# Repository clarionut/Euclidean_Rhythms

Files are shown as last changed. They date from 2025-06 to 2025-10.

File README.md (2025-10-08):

# Euclidean Rhythms
Euclidean Rhythms

This repository contains details of my derivative of [Hagiwo's Euclidean Rhythms](https://note.com/solder_state/n/n433b32ea6dbc) synthesiser module.

In his notes about the module, Hagiwo comments that there is considerable latency due to the OLED display and also mentions instability in the program
possibly caused by memory issues. He partially addresses the latency issue by only updating the OLED on clock inputs, but this makes it difficult to
update the settings in the absence of a clock input.
During analysis of the code I found several things which would compound these issues, e.g.
- use of a relatively slow I2C OLED display. Swapped for an alternative using much faster hardware SPI
- (using a graphics library which keeps an in-memory copy of the display. Changed to the less memory-intensive U8glib library). Subsequent testing has shown that code using the Adafruit_SSD1306 library runs roughly twice as fast as either u8glib or u8g2. I'd therefore recommend using the EuclideanRhythms_AF sketch. It's larger than the u8glib based code but has shown no signs of instability despite its greater functionality
- the original code uses multiple loops over the channels, each processing a single aspect of the code. Restructured to carry out as many of these
operations as possible in a single loop
- use of the Arduino digitalWrite() function (intrinsically very slow) to output the triggers. Replaced by direct port operations to update all trigger
outputs much faster and simultaneously
- the rotary encoder originally used both interrupt pins of the Arduino with simple polling of the clock input, potentially leading to short clock pulses
being missed. The Encoder library can also be used in a single-interrupt mode allowing the clock input to use the other interrupt, with the interrupt
service routine directly generating the trigger outputs

These changes significantly improve the performance and allow the display to be updated on each clock and when the rotary encoder is used. The display
update is still relatively slow even using hardware SPI resulting in long & variable length trigger outputs. Also the OLED is always on even if the
module is not in use. I therefore added a screensaver which blanks the OLED after 30 seconds plus LEDs to monitor the trigger outputs. The OLED is
enabled again when the rotary encoder is used. This allows quite high clock speeds once the screensaver has kicked in.

Some extra functionality has been added to the code:
- ability to 'Put' the current settings into the Arduino EEPROM and 'Get' them from EEPROM in a subsequent session. This version of the code starts up
with predefined default settings, but it would be easy to modify so that the stored settings are retrieved automatically at start up
- a probability control by potentiometer or input CV to vary the likelyhood of changes in Random mode. As in Hagiwo's original code the allowed ranges
of randomness are predefined in the code with the probability controls influencing how likely the changes are
- option for a gate input to re-zero all the output channels to the starting position. I didn't implement this hardware due to a lack of space on my
Eurorack panel but the code for it is present

There are some more details of the changes in the Arduino code comments. The hardware is similar to the original but uses an Arduino Pro Mini rather than
a Nano, has buffering on the outputs for protection and to give higher voltage triggers, and has additional circuitry for the probability controls &
manual step button.

Please note that I built this module using stripboard rather than a PCB. The KiCad files and Gerbers have been used to build an [SPI version of Hagiwo's 6-channel trigger sequencer](https://github.com/clarionut/6-channel-trg-sequencer) so the PCB layout has now been verified apart from the probability CV input section.

### Updates
08-10-2025 - updated KiCad files (amended silk-screen labelling, minor header-pin changes); added Arduino code using the faster Adafruit_SSD1306 library - RECOMMENDED

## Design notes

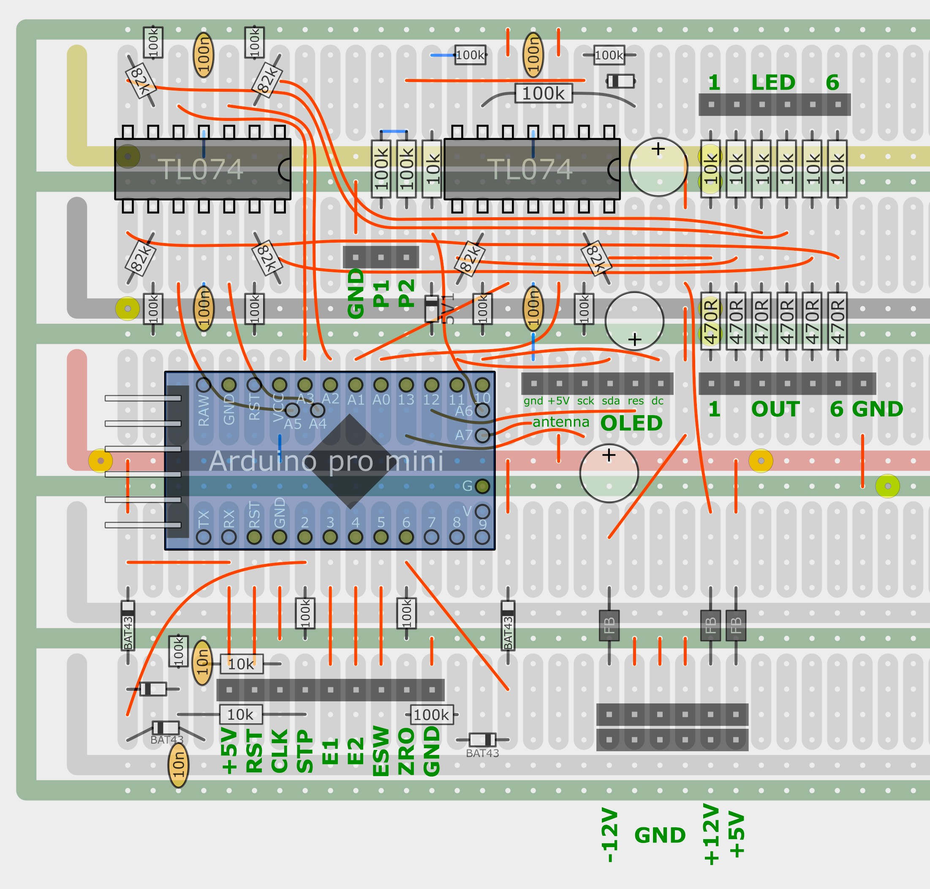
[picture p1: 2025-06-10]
Schematics/Stripboard.png

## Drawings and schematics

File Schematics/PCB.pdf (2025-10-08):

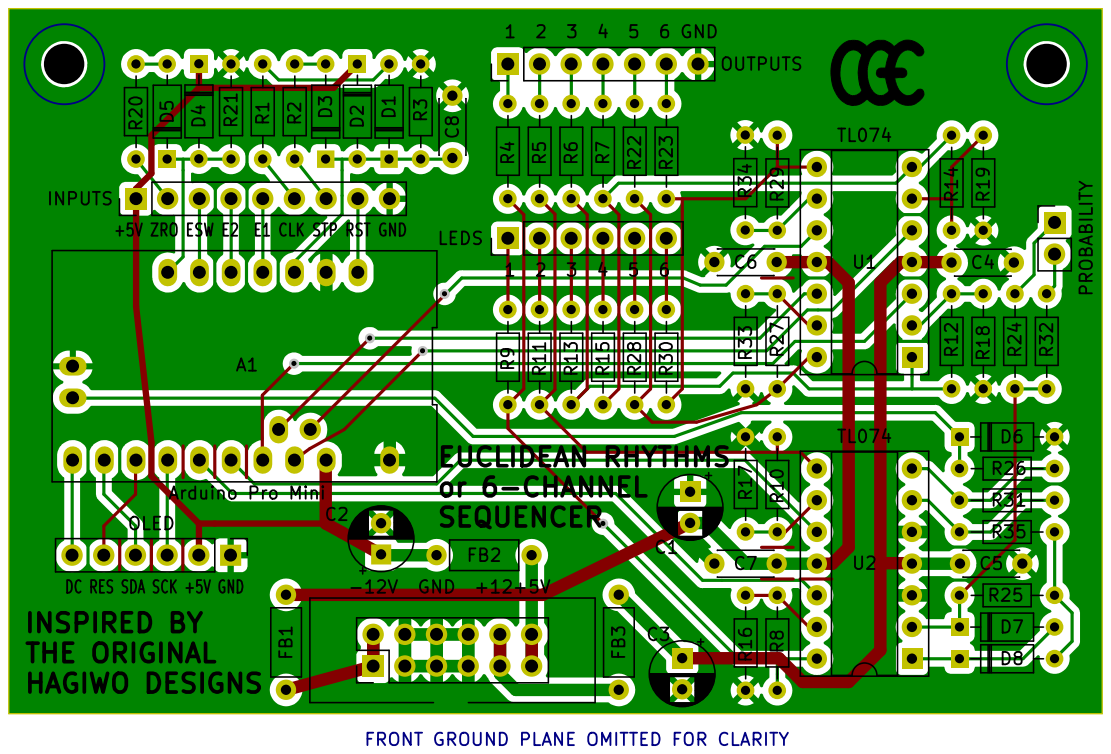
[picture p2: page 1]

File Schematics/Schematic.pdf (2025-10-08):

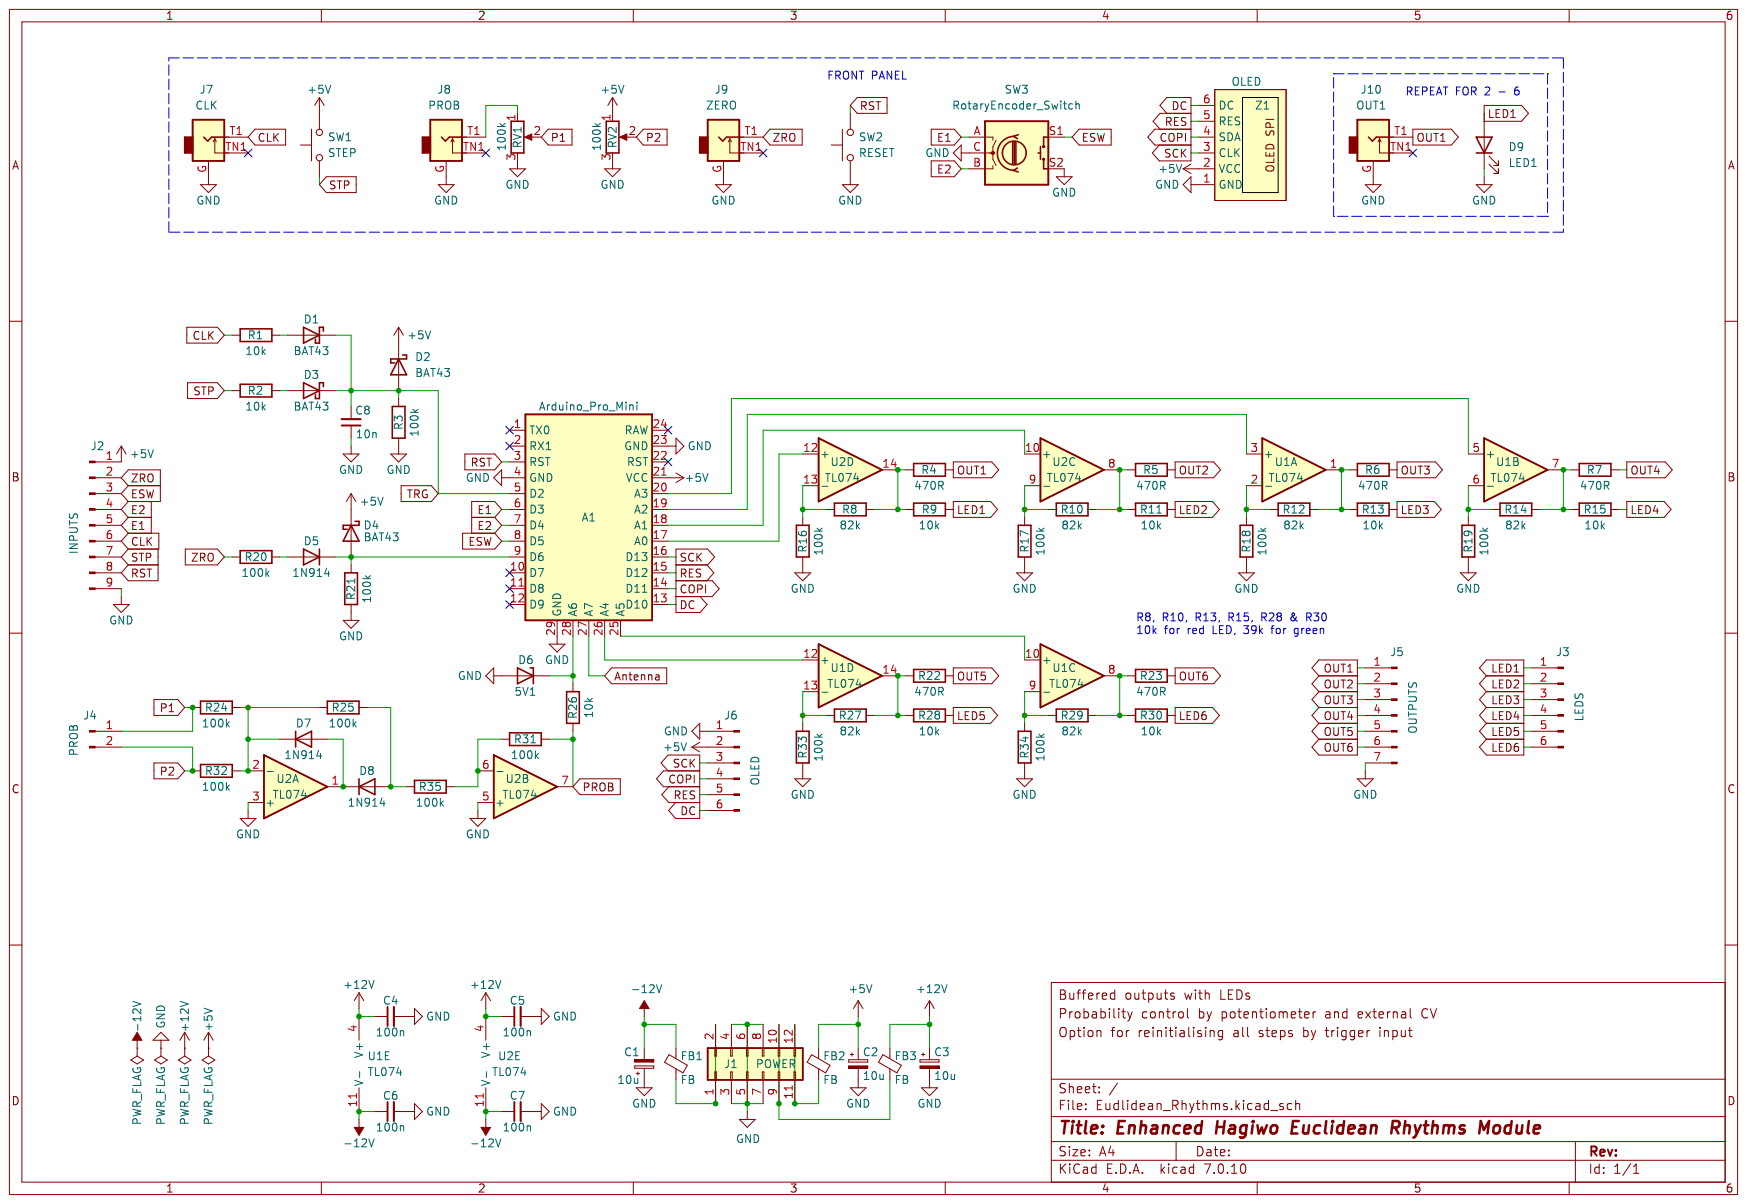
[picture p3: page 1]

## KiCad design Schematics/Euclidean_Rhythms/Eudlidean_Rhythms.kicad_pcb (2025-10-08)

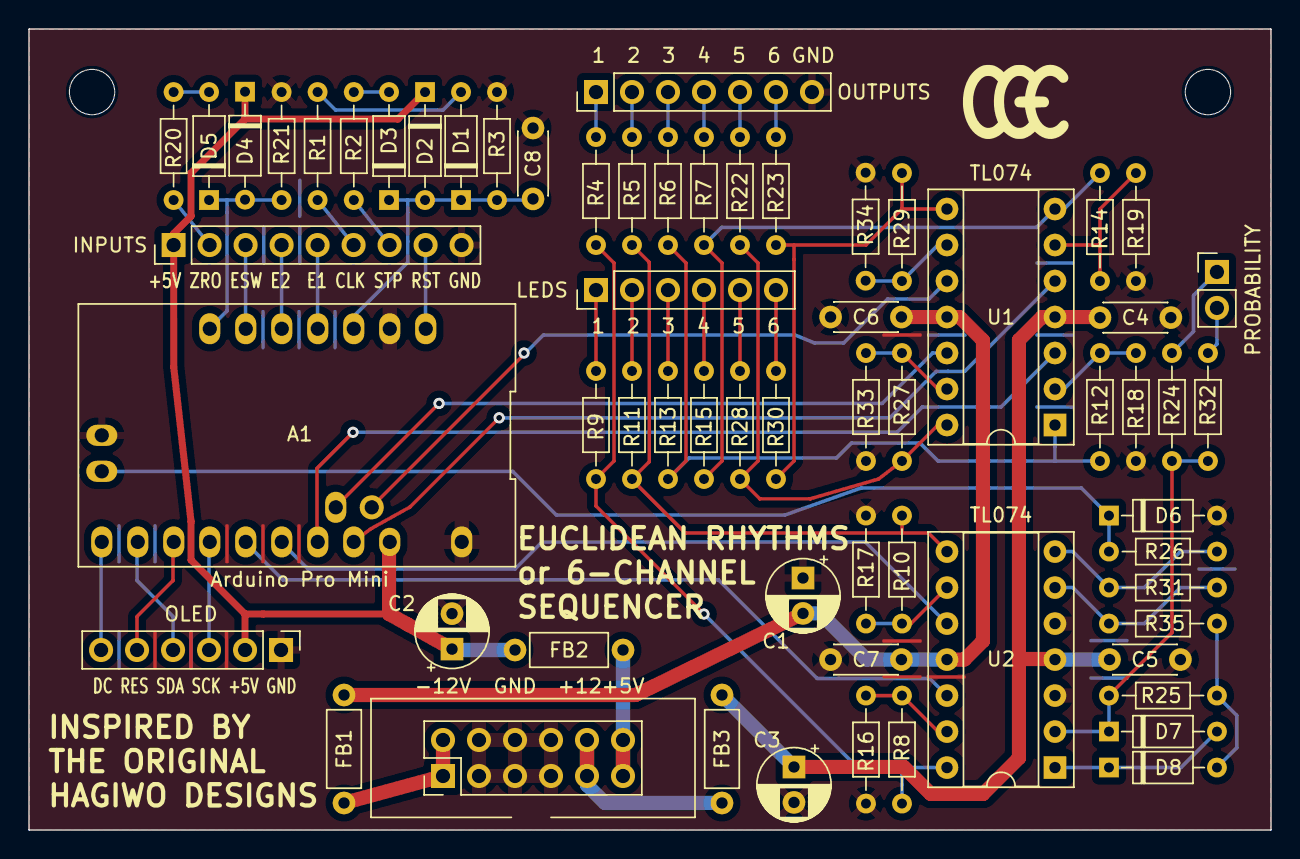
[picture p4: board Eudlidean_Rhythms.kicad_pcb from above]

Board: 2 copper layers, 87.6 x 56.5 mm, 63 parts (0 on the bottom side), 61 nets.

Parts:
A1: Arduino_Pro_Mini
C1, C2, C3: 10u; CP_Radial_D5.0mm_P2.50mm
C4, C5, C6, C7: 100n; C_Disc_D4.3mm_W1.9mm_P5.00mm
C8: 10n; C_Disc_D4.3mm_W1.9mm_P5.00mm
D1, D2, D3, D4: BAT43; D_DO-35_SOD27_P7.62mm_Horizontal
D5, D7, D8: 1N914; D_DO-35_SOD27_P7.62mm_Horizontal
D6: 5V1; D_DO-35_SOD27_P7.62mm_Horizontal
FB1, FB2, FB3: FB; L_Axial_L5.3mm_D2.2mm_P7.62mm_Horizontal_Vishay_IM-1
J1: POWER; Power_2x06
J2: INPUTS; PinHeader_1x09_P2.54mm_Vertical
J3: LEDS; PinHeader_1x06_P2.54mm_Vertical
J4: PROB; PinHeader_1x02_P2.54mm_Vertical
J5: OUTPUTS; PinHeader_1x07_P2.54mm_Vertical
J6: OLED; PinHeader_1x06_P2.54mm_Vertical
R1, R2, R9, R11, R13, R15, R26, R28, R30: 10k; R_Axial_DIN0204_L3.6mm_D1.6mm_P7.62mm_Horizontal
R3, R16, R17, R18, R19, R20, R21, R24, R25, R31, R32, R33, R34, R35: 100k; R_Axial_DIN0204_L3.6mm_D1.6mm_P7.62mm_Horizontal
R4, R5, R6, R7, R22, R23: 470R; R_Axial_DIN0204_L3.6mm_D1.6mm_P7.62mm_Horizontal
R8, R10, R12, R14, R27, R29: 82k; R_Axial_DIN0204_L3.6mm_D1.6mm_P7.62mm_Horizontal
U1, U2: TL074; DIP-14_W7.62mm_Socket

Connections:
+5V: A1.21 (VCC), C2.1, D2.1 (K), D4.1 (K), FB2.1, J2.1, J6.2
+12V: C3.1, C4.1, C5.1, FB3.1, U1.4 (V+), U2.4 (V+)
-12V: C1.2, C6.1, C7.1, FB1.1, U1.11 (V-), U2.11 (V-)
CLK: J2.6, R1.1
COPI: A1.14 (D11), J6.4
DC: A1.13 (D10), J6.6
E1: A1.6 (D3), J2.5
E2: A1.7 (D4), J2.4
ESW: A1.8 (D5), J2.3
GND: A1.4 (GND), A1.23 (GND), A1.29 (GND), C1.1, C2.2, C3.2, C4.2, C5.2, C6.2, C7.2, C8.1, D6.2 (A), J1.3, J1.4, J1.5, J1.6, J1.7, J1.8, J2.9, J5.7, J6.1, R3.1, R16.1, R17.1, R18.1, R19.1, R21.1, R33.1, R34.1, U2.3 (+), U2.5 (+)
LED1: J3.1, R9.2
LED2: J3.2, R11.2
LED3: J3.3, R13.2
LED4: J3.4, R15.2
LED5: J3.5, R28.2
LED6: J3.6, R30.2
unnamed: A1.17 (A0), U2.12 (+)
unnamed: A1.18 (A1), U2.10 (+)
unnamed: A1.19 (A2), U1.3 (+)
unnamed: A1.20 (A3), U1.5 (+)
unnamed: A1.26 (A4), U1.12 (+)
unnamed: A1.25 (A5), U1.10 (+)
unnamed: A1.28 (A6), D6.1 (K), R26.2
unnamed: A1.9 (D6), D4.2 (A), D5.1 (K), R21.2
unnamed: D1.2 (A), R1.2
unnamed: D3.2 (A), R2.2
unnamed: D5.2 (A), R20.2
unnamed: D7.2 (A), D8.1 (K), U2.1
unnamed: D7.1 (K), R24.2, R25.1, R32.2, U2.2 (-)
unnamed: D8.2 (A), R25.2, R35.1
unnamed: FB1.2, J1.1, J1.2
unnamed: FB3.2, J1.9, J1.10
unnamed: FB2.2, J1.11, J1.12
unnamed: R4.1, R8.2, R9.1, U2.14
unnamed: R5.1, R10.2, R11.1, U2.8
unnamed: R6.1, R12.2, R13.1, U1.1
unnamed: R7.1, R14.2, R15.1, U1.7
unnamed: R22.1, R27.2, R28.1, U1.14
unnamed: R23.1, R29.2, R30.1, U1.8
unnamed: R12.1, R18.2, U1.2 (-)
unnamed: R14.1, R19.2, U1.6 (-)
unnamed: R29.1, R34.2, U1.9 (-)
unnamed: R27.1, R33.2, U1.13 (-)
unnamed: R31.1, R35.2, U2.6 (-)
unnamed: R10.1, R17.2, U2.9 (-)
unnamed: R8.1, R16.2, U2.13 (-)
OUT1: J5.1, R4.2
OUT2: J5.2, R5.2
OUT3: J5.3, R6.2
OUT4: J5.4, R7.2
OUT5: J5.5, R22.2
OUT6: J5.6, R23.2
P1: J4.1, R24.1
P2: J4.2, R32.1
PROB: R26.1, R31.2, U2.7
RES: A1.15 (D12), J6.5
RST: A1.3 (RST), J2.8
SCK: A1.16 (D13), J6.3
STP: J2.7, R2.1
TRG: A1.5 (D2), C8.2, D1.1 (K), D2.2 (A), D3.1 (K), R3.2
ZRO: J2.2, R20.1

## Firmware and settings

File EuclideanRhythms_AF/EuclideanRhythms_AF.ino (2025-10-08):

/*
  Code for a modified version of Hagiwo's excellent Euclidean Rhythm generator
  (https://note.com/solder_state/n/n433b32ea6dbc)
  
  Hardware modifications:
  - SPI rather than I2C OLED display for speed, using Adafruit_SSD1306 hardware SPI
    (Note: as of 16/09/2025, the Adafruit library is ~2x faster than either u8glib or u8g2)
  - buffered outputs plus LEDs
  - random mode probability control via potentiometer and external CV
  - gate input to zero all step counters using voltage control

  Software modifications:
  - code restructured for efficiency
  - uses direct port manipulation to speed up and synchronise trigger output
  - fixed problems with 1-hit mode (line rotated wrong way on offset, consequently
    not matching step/hit markers)
  - menus wrap around, encoder button autorepeats
  - resets current step to 0 when the number of steps rolls around to zero
  - doesn't display step circle if the number of hits or number of steps is zero
  - renamed menu items L(imit) to S(teps) and R(eset) to Z(ero)
  - pattern settings can be stored for retrieval in a subsequent session using P(ut)
    into and G(et) from EEPROM, in both the channel and random menus
  - runs rotary encoder in single-interrupt mode using pins 3 (interrupt) and 4
  - handles incoming triggers on pin 2 using an interrupt service routine, allowing
    screen refresh immediately on menu changes without compromising timing
  - screen saver blanks display after specified period, wakes on rotary encoder
    rotation or button, can be disabled if desired
  - option for zeroing all channels simultaneously by gate input
*/

#include <Encoder.h>
#include <EEPROM.h>

#include <SPI.h>
#include <Adafruit_GFX.h>
#include <Adafruit_SSD1306.h>
#define SCREEN_WIDTH 128
#define SCREEN_HEIGHT 64
#define OLED_RESET 12

// Screen Saver timeout in seconds (comment out next line to disable screen saver)
#define SS_TIMEOUT 30

// Uncomment next line to enable code for a 'zero all steps' gate input
//#define ZRO_PIN 6

// Pin definitions. CLK_PIN MUST be an interrupt-enabled pin (2 or 3 on an Arduino Pro mini)
#define BTN_PIN 5
#define CLK_PIN 2

// OLED connections using hardware SPI
Adafruit_SSD1306 display(SCREEN_WIDTH, SCREEN_HEIGHT, &SPI, 10, 12, -1); // SCK = 13, COPI = 11, D/C = 10, RST = 12, CS not used

// rotary encoder in single-interrupt mode (pin 3)
Encoder encoder(3, 4);
int oldEnc = -999; 
int newEnc = -999;
unsigned long encMillis; // for screen saver

// screen saver
bool screenSave = 0;
#ifdef SS_TIMEOUT
const unsigned long ssTimeout = SS_TIMEOUT * 1000;
#else
const unsigned long ssTimeout = 0;
#endif

#ifdef ZRO_PIN
// zero pin
bool zero = 0;
bool oldZero = 0;
#endif

// encoder button
unsigned long encBtn_millis = 0; // for debounce / autorepeat

// flag for trigger processed in ISR
volatile bool triggered = 0;

// Initial parameters for each channel
// The startup configuration can be changed by altering these values
uint8_t numHits[6]  = { 4, 4, 5, 3, 2, 16 };      // number of hits
uint8_t offset[6]   = { 0, 2, 0, 8, 3, 9 };       // hit offsets
bool    mute[6]     = { 0, 0, 0, 0, 0, 0 };       // 0 = unmuted, 1 = muted
uint8_t numSteps[6] = { 16, 16, 16, 16, 16, 16 }; // enabled steps

// Probabilities of change in random mode
//   With the probability control set to the middle of its range
//   these are the % probabilities that randomisation will occur
// Adjust these values to modify the probabilities of change
const uint8_t hitProb[6]    = {  0, 10, 20, 40, 40, 20 };
const uint8_t offsetProb[6] = {  0, 20, 20, 20, 40, 20 };
const uint8_t muteProb[6]   = { 20, 20, 20, 20, 20, 20 };
const uint8_t hitRngMax[6]  = {  4,  6, 16,  8,  9, 16 };
const uint8_t hitRngMin[6]  = {  4,  1,  6,  1,  5, 10 };

// The 17 Euclidian rhythm patterns of 16 steps
const static uint8_t Euclid[17][16] PROGMEM = {
  { 0, 0, 0, 0, 0, 0, 0, 0, 0, 0, 0, 0, 0, 0, 0, 0 },
  { 1, 0, 0, 0, 0, 0, 0, 0, 0, 0, 0, 0, 0, 0, 0, 0 },
  { 1, 0, 0, 0, 0, 0, 0, 0, 1, 0, 0, 0, 0, 0, 0, 0 },
  { 1, 0, 0, 0, 0, 1, 0, 0, 0, 0, 1, 0, 0, 0, 0, 0 },
  { 1, 0, 0, 0, 1, 0, 0, 0, 1, 0, 0, 0, 1, 0, 0, 0 },
  { 1, 0, 0, 1, 0, 0, 1, 0, 0, 1, 0, 0, 1, 0, 0, 0 },
  { 1, 0, 0, 1, 0, 1, 0, 0, 1, 0, 0, 1, 0, 1, 0, 0 },
  { 1, 0, 0, 1, 0, 1, 0, 1, 0, 0, 1, 0, 1, 0, 1, 0 },
  { 1, 0, 1, 0, 1, 0, 1, 0, 1, 0, 1, 0, 1, 0, 1, 0 },
  { 1, 0, 1, 1, 0, 1, 0, 1, 0, 1, 1, 0, 1, 0, 1, 0 },
  { 1, 0, 1, 1, 0, 1, 0, 1, 1, 0, 1, 1, 0, 1, 0, 1 },
  { 1, 0, 1, 1, 0, 1, 1, 0, 1, 1, 0, 1, 1, 0, 1, 1 },
  { 1, 0, 1, 1, 1, 0, 1, 1, 1, 0, 1, 1, 1, 0, 1, 1 },
  { 1, 0, 1, 1, 1, 1, 0, 1, 1, 1, 1, 0, 1, 1, 1, 1 },
  { 1, 0, 1, 1, 1, 1, 1, 1, 1, 0, 1, 1, 1, 1, 1, 1 },
  { 1, 1, 1, 1, 1, 1, 1, 1, 1, 1, 1, 1, 1, 1, 1, 0 },
  { 1, 1, 1, 1, 1, 1, 1, 1, 1, 1, 1, 1, 1, 1, 1, 1 }
};
bool pattern[6][16]; // offset buffer, Stores the offset result

volatile uint8_t playingStep[6] = { 0, 0, 0, 0, 0, 0 }; // playing step number for channels 1 -> 6
volatile unsigned long trgMillis = 0; // for output trigger length and display blanking
uint8_t trgLen = 4; // trigger length in milliseconds - sets to 10ms when screensave active

// Display parameters
int8_t  selectMenu = 0; // 0 = channel/random, 1 = hits/numBars, 2 = offset/get, 3 = numSteps/put, 4 = mute, 5 = zero, 6 = get, 7 = put
uint8_t selectChnl = 0; // 0 -> 5 = channels 1 -> 6, 6 = random mode
bool   dispRefresh = 1; // 1 = refresh display this pass, 0 = no refresh

// Offsets for the channels' Euclidean displays
const uint8_t positionX[6] = { 0, 40, 80, 13, 53, 93 };
const uint8_t positionY[6] = { 0,  0,  0, 33, 33, 33 };

// Vertex coordinates
const uint8_t vertexX[16] = { 15, 21, 26, 29, 30, 29, 26, 21, 15,  9,  4,  1,  0,  1,  4,  9 };
const uint8_t vertexY[16] = {  0,  1,  4,  9, 15, 21, 26, 29, 30, 29, 26, 21, 15,  9,  4,  1 };

uint8_t stepCnt = 0; // step count
uint8_t barNow = 1; // current bar; increases by one after 16 steps
const uint8_t barMax[4] = { 2, 4, 8, 16 }; // mumber of bars to stay fixed in random mode
uint8_t barSelect = 1; // selected initial barMax value

void setup() {

  display.begin(SSD1306_SWITCHCAPVCC, 0, 1);

  // Pin modes
  pinMode(BTN_PIN, INPUT_PULLUP);
  pinMode(CLK_PIN, INPUT);
  pinMode(14, OUTPUT); // A0: channel 1
  pinMode(15, OUTPUT); // A1: channel 2
  pinMode(16, OUTPUT); // A2: channel 3
  pinMode(17, OUTPUT); // A3: channel 4
  pinMode(18, OUTPUT); // A4: channel 5
  pinMode(19, OUTPUT); // A5: channel 6

  attachInterrupt(digitalPinToInterrupt(CLK_PIN), handleTrigger, RISING);

  // Set up the OLED display
  display.setTextSize(0); // Output character size
  display.setTextColor(WHITE); // Output text color
  display.clearDisplay();
  display.display();

  encMillis = millis();
}

void loop() {
#ifdef ZRO_PIN
  //----------------Gate on Zero pin---------------------
  zero = digitalRead(ZRO_PIN);
  if (zero && !oldZero) {
    oldZero = 1;
    for (uint8_t k = 0; k < 6; k++) {
      playingStep[k] = 0;
    }
  } else if (!zero && oldZero) {
    oldZero = 0;
  }
#endif

  //-----------------Rotary encoder----------------------
  newEnc = encoder.read();
  if (newEnc < oldEnc - 3) { // turn left by one detent
    oldEnc = newEnc;
    encMillis = millis();
    if (screenSave) {
      screenSave = 0;
      trgLen = 4;
    } else {
      --selectMenu;
    }

  } else if (newEnc > oldEnc + 3) { // turn right by one detent
    oldEnc = newEnc;
    encMillis = millis();
    if (screenSave) {
      screenSave = 0;
      trgLen = 4;
    } else {
      ++selectMenu;
    }
  }

  if (!screenSave) {
    // Update the current menu item
    if (6 == selectChnl) { // random mode
      if (selectMenu > 3) selectMenu = 0;
      else if (selectMenu < 0) selectMenu = 1;
    } else { // channel mode
      if (selectMenu > 7) selectMenu = 0;
      else if (selectMenu < 0) selectMenu = 7;
    }
  }
  
  //-----------------Encoder button----------------------
  if (!digitalRead(BTN_PIN) && (millis() - encBtn_millis >= 400)) { // button pressed outside debounce/autorepeat period
    encBtn_millis = millis();
    encMillis = millis();

    if (screenSave) {
      screenSave = 0;
      trgLen = 4;

    } else {
      switch (selectMenu) {
        case 0: // select channel
          ++selectChnl;
          selectChnl %= 7;
          break;

        case 1: // increment number of hits (channel mode) or number of bars (random mode)
          if (selectChnl != 6) { // channel mode
            ++numHits[selectChnl];
            numHits[selectChnl] %= 17;

          } else { // random mode
            ++barSelect;
            barSelect %= 4;
          }
          break;

        case 2: // increment offset (channel mode) or get from EEPROM (random mode)
          if (selectChnl != 6) { // channel mode
            ++offset[selectChnl];
            offset[selectChnl] %= 16;

          } else { // random mode
            getFromEEPROM();
          }
          break;

        case 3: // increment number of steps (channel mode) or put into EEPROM (random mode)
          if (selectChnl != 6) { // channel mode
            ++numSteps[selectChnl];
            numSteps[selectChnl] %= 17;
            if (playingStep[selectChnl] > numSteps[selectChnl]) playingStep[selectChnl] = 0;

          } else { // random mode
            putIntoEEPROM();
          }
          break;

        case 4: // toggle mute
          mute[selectChnl] = !mute[selectChnl] ;
          break;

        case 5: // reset to step 0 on all channels
          for (uint8_t k = 0; k < 6; k++) {
            playingStep[k] = 0;
          }
          break;

        case 6: // Get stored settings from EEPROM
          getFromEEPROM();
          break;

        case 7: // Put current settings into EEPROM
          putIntoEEPROM();
          break;
      }
    }
  }

  //------------update steps and bars after trigger processing-------------
  if (triggered) {
    triggered = 0;

    if (6 == selectChnl) { // random mode setting
      ++stepCnt;
      if (stepCnt > 15) {
        ++barNow;
        stepCnt = 0;
        if (barNow > barMax[barSelect]) {
          barNow = 1;
          randomChange();
        }
      }
    }
    dispRefresh = 1;
  }

  //-----------------set channel patterns----------------------
  for (uint8_t k = 0; k < 6; k++) { // k = channels 1 -> 6
    for (uint8_t j = offset[k]; j < 16; j++) {
      pattern[k][j - offset[k]] = pgm_read_byte(&Euclid[numHits[k]][j]);
    }

    for (uint8_t j = 0; j < offset[k]; j++) {
      pattern[k][16 - offset[k] + j] = pgm_read_byte(&Euclid[numHits[k]][j]);
    }
  }
  //dispRefresh = 1;

  if (millis() - trgMillis > trgLen) { // turn off triggers after 5ms
    PORTC = 0;
  }

  if (dispRefresh || (millis() - trgMillis > 500)) {
    OLED_display();
    dispRefresh = 0;
  }
}

void randomChange() {
  // Called in random mode when barNow is reset

  // Configured so a 0V probability input will fix the patterns,
  // 50% gives about the same probability as the original Hagiwo code
  // and 100% gives about double the chance of change
  unsigned long mult = 1L + (unsigned long) analogRead(A6);
  for (uint8_t k = 0; k < 6; k++) {
    if ((mult * (unsigned long) hitProb[k]) >> 9 >= random(1, 100)) { // random change of numHits
      numHits[k] = random(hitRngMin[k], hitRngMax[k] + 1);
    }

    if ((mult * (unsigned long) offsetProb[k]) >> 9 >= random(1, 100)) { // random change of offset
      offset[k] = random(0, 16);
    }

    mute[k] = ((mult * (unsigned long) muteProb[k]) >>9 >= random(1, 100)); // random change of mute
  }
}

void OLED_display() {
  display.clearDisplay();

#ifdef SS_TIMEOUT
  if (!screenSave && millis() - encMillis > ssTimeout) {
    // Blank screen the specified period after the last encoder operation
    screenSave = 1;
    trgLen = 10;
    display.display();
  }
  if (screenSave) return;
#endif

  if (selectChnl != 6) { // channel mode menu
    display.setCursor(120, 0);
    display.print(selectChnl + 1);
    display.setCursor(120, 8);
    display.print("H");
    display.setCursor(120, 16);
    display.print("O");
    display.setCursor(120, 24);
    display.print("S");
    display.setCursor(0, 33);
    display.print("M");
    display.setCursor(0, 41);
    display.print("Z");
    display.setCursor(0, 49);
    display.print("G");
    display.setCursor(0, 57);
    display.print("P");

  } else { // random mode menu
    display.setCursor(120, 0);
    display.print("R");
    display.setCursor(120, 8);
    display.print("L");
    display.setCursor(120, 16);
    display.print("G");
    display.setCursor(120, 24);
    display.print("P");
    display.drawRect(0, 62 - barMax[barSelect] * 2, 6, barMax[barSelect] * 2 + 1, WHITE);
    display.fillRect(0, 63 - barNow * 2 , 6, barMax[barSelect] * 2 + 1, WHITE);
  }

  // draw menu select triangle
  switch (selectMenu) {
    case 0:
      display.fillTriangle(113, 0, 113, 6, 118, 3, WHITE);
      break;
    case 1:
      display.fillTriangle(113, 8, 113, 14, 118, 11, WHITE);
      break;
    case 2:
      display.fillTriangle(113, 16, 113, 22, 118, 19, WHITE);
      break;
    case 3:
      display.fillTriangle(113, 24, 113, 30, 118, 27, WHITE);
  }
  if (selectChnl != 6) { // channel mode
    switch (selectMenu) {
      case 4:
        display.fillTriangle(12, 34, 12, 40, 7, 37, WHITE);
        break;
      case 5:
        display.fillTriangle(12, 42, 12, 48, 7, 45, WHITE);
        break;
      case 6:
        display.fillTriangle(12, 50, 12, 56, 7, 53, WHITE);
        break;
      case 7:
        display.fillTriangle(12, 58, 12, 64, 7, 61, WHITE);
    }
  }

  // draw step dots
  for (uint8_t k = 0; k < 6; k++) {
    for (uint8_t j = 0; j <= numSteps[k] - 1; j++) { // j = steps
      display.drawPixel(vertexX[j] + positionX[k], vertexY[j] + positionY[k], WHITE);
    }
  }

  // draw hits lines
  for (uint8_t k = 0; k < 6; k++) {
    uint8_t lineXbuf[17]; // Buffers for drawing lines
    uint8_t lineYbuf[17];
    uint8_t vertexCount = 0;
    uint8_t j;
    for (j = 0; j < 16; j++) {
      if (pattern[k][j]) {
        // calculate screen coordinates of the current pattern's vertices
        lineXbuf[vertexCount] = vertexX[j] + positionX[k];
        lineYbuf[vertexCount] = vertexY[j] + positionY[k];
        ++vertexCount;
      }
    }

    if (numHits[k] > 1) { // 2 -> 16 hits - draw n-gon
      for (j = 0; j < vertexCount - 1; j++) {
        display.drawLine(lineXbuf[j], lineYbuf[j], lineXbuf[j + 1], lineYbuf[j + 1], WHITE);
      }
      display.drawLine(lineXbuf[0], lineYbuf[0], lineXbuf[j], lineYbuf[j], WHITE);

    } else if (1 == numHits[k]) { // 1 hit - draw line from centre
      display.drawLine(15 + positionX[k], 15 + positionY[k], lineXbuf[0], lineYbuf[0], WHITE);
    }

  // draw play step circle unless muted or numSteps==0
    if (!mute[k] && numSteps[k]) {
      if (pattern[k][playingStep[k]]) {
        display.fillCircle(vertexX[playingStep[k]] + positionX[k], vertexY[playingStep[k]] + positionY[k], 2, WHITE);
      } else {
        display.drawCircle(vertexX[playingStep[k]] + positionX[k], vertexY[playingStep[k]] + positionY[k], 2, WHITE);
      }
    }
  }
  display.display();
}

void handleTrigger(void) {
  trgMillis = millis();
  uint8_t port = 0;
  for (uint8_t j = 0; j < 6; j++) {
    ++playingStep[j]; // increment the step count on an incoming trigger
    playingStep[j] %= numSteps[j];
    if ((1 == pattern[j][playingStep[j]]) && !mute[j]) {
      port |= 64;
    }
    port >>= 1;
  }
  PORTC = port;

  triggered = 1;
}

void getFromEEPROM(void) {
  // values are interleaved for efficiency in reading and writing
  if (EEPROM.read(0) != 255) { // EEPROM contains data
    noInterrupts();
    uint16_t address = 0;
    for (uint8_t k = 0; k < 6; k++) {
      for (uint8_t j = 0; j < 16; j++) {
        pattern[k][j] = EEPROM.read(address++);
      }
      numHits[k] = EEPROM.read(address++);
      offset[k] = EEPROM.read(address++);
      mute[k] = EEPROM.read(address++);
      numSteps[k] = EEPROM.read(address++);
      playingStep[k] = EEPROM.read(address++);
    }
    selectChnl = EEPROM.read(address++);
    stepCnt = EEPROM.read(address++);
    barNow = EEPROM.read(address++);
    barSelect = EEPROM.read(address++);
    interrupts();
  }
}

void putIntoEEPROM(void) {
  // values are interleaved for efficiency in reading and writing
  noInterrupts();
  uint16_t address = 0;
  for (uint8_t k = 0; k < 6; k++) {
    for (uint8_t j = 0; j < 16; j++) {
      EEPROM.update(address++, pattern[k][j]);
    }
    EEPROM.update(address++, numHits[k]);
    EEPROM.update(address++, offset[k]);
    EEPROM.update(address++, mute[k]);
    EEPROM.update(address++, numSteps[k]);
    EEPROM.update(address++, playingStep[k]);
   }
  EEPROM.update(address++, selectChnl);
  EEPROM.update(address++, stepCnt);
  EEPROM.update(address++, barNow);
  EEPROM.update(address++, barSelect);
  interrupts();
}
